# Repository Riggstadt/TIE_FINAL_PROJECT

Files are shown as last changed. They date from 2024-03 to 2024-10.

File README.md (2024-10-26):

# TIE FINAL PROJECT

This project was meant to familiarize us with PCB layout best practices and Design for Manufacturing (DFM).
<br>
  <p align="center">
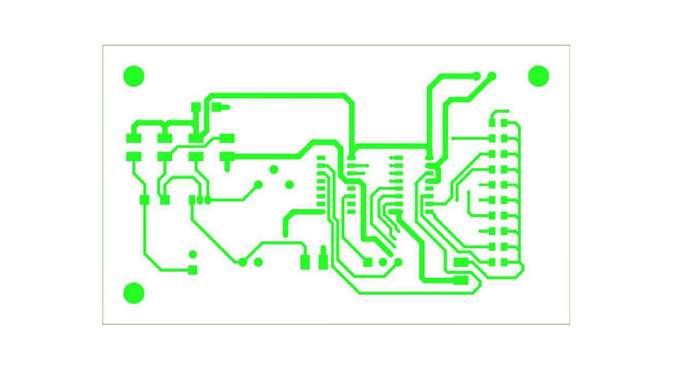
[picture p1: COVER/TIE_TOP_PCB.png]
    
    <br>
    <a><b>Top signal layer of PCB</b></a>
</p>
<br>

The final product of this project was a set of manufacturing files for PCB production, which was accompanied by a thorough technical documentation concerning circuit functionality and board design optimizations. 

This project served as the pelude to further PCB projects during my Electrotechnical Engineering degree, one of which can be seen <a href="https://github.com/Riggstadt/PROIECT_1_ETTI/tree/main">here</a>.

<br>
  <p align="center">
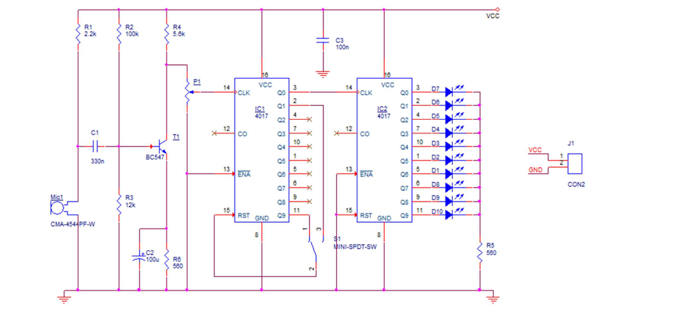
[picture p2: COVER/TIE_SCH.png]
    
    <br>
    <a><b>Circuit Schematic of Light Organ</b></a>
</p>
<br>

For a complete picture of the project, including sources and part inventory, please consult <a href="Orga de lumini.pdf">the documentation</a>.

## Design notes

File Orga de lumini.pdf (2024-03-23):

# UNIVERSITATEA POLITEHNICA DIN BUCUREȘTI

# ORGĂ DE LUMINI CU LED-URI

# Studenți: Frunză Vladimir, 423B Roncea Teodor Virgil, 423B

# Coordonator: Prof. Dr. Ing. Norocel Dragoș Codreanu An universitar: 2022-2023 Data de predare: 08.06.2023

## Facultatea de Electronică, Telecomunicații și Tehnologia Informației Departamentul de Electronică Tehnologică și Tehnici de Interconectare

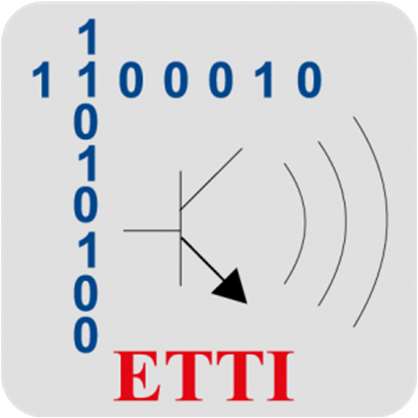
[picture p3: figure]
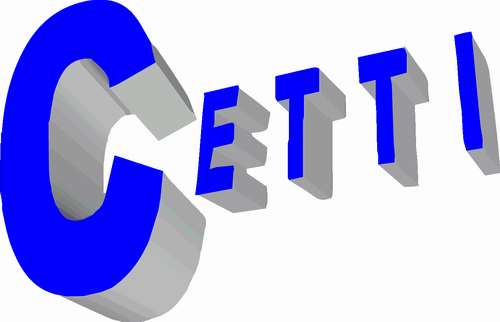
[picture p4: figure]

# CUPRINS

### I. Date iniale de proiectare | 1

II. | Descrierea a funconarii schemei proiectate | 2
III. | Schema electrica | 5
IV. | Design Rules Check (DRC) | 6

V. Cross Reference (CR) | 7 VI. Bill of Materials (BOM) | 9 VII. Wirelist (WR) | 10 VIII. Verificarea net-urilor | 16 IX. Layer TOP | 17 X. Layer BOTTOM | 18 XI. Layer Solder Mask TOP | 19 XII. Layer Solder Mask BOTTOM | 20 XIII. Layer Silk Screen TOP | 21 XIV. Layer Assembly Drawing TOP | 22 XV. Layer Fabricaon | 23 XVI. Concluzii | 24 XVII. Bibliografie | 25 XVIII. ANEXE | 26

# I. Date iniale de proiectare

Scopul proiectului de fata este de a realiza design-ul PCB al unei orgi de lumini cu LED-uri, conform unei scheme electrice si ai unor parametrii dati. Orga de lumini este realizata din mai multe blocuri functionale: captare semnal, amplificare semnal, reglare sensibilitate, divizor de frecventa si baterie de LED-uri.

PCB-ul o sa fie realizat din doua straturi electrice, TOP si BOTTOM. Toate componentele electrice vor fi plasate pe stratul TOP, traseele de semnal vor avea latimea de 0.5 mm, traseele de alimentare vor avea latimea de 0.9 mm, conexiunea cu masa se va realiza prin intermediul unor trasee de putere individuale, iar spatierea in toate cazurile va fi de 0.35 mm.

Placa va fi una dreptunghiulara cu latimea de 45 mm si lungimea de 75 mm, se vor plasa trei gauri de prindere nemetalizate cu un diametru de 3.2mm. Fiecare gaura se va afla la o distanta de 2M de coltul in care a fost plasat. Constrangerile de proiectare se pot vedea in ANEXA 2, randul 8.

In capitolele ce urmeaza se va prezenta o scurta descriere a circuitului, schema electrica echivalenta in programul OrCAD Capture si straturile electrice si non-electrice ale PCB-ului.

Schema electrica de realizat:

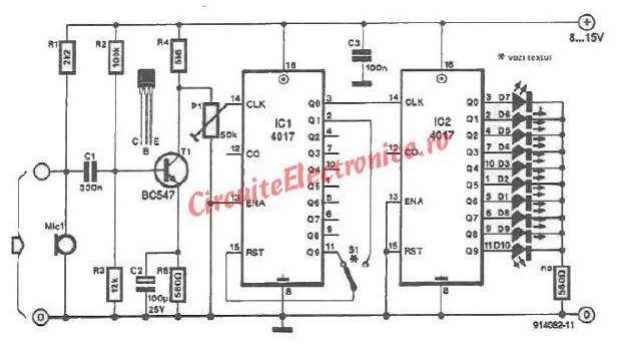
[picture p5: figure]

# II. Descriere a funconarii schemei proiectate

## a. Explicae la nivel general:

Circuitul din schema prezentata este al unei orgi de lumini cu LED-uri. Orga noastra produce jocul de lumini prin prelucrarea si “interpretarea” sunetelor prezente in mediul inconjurator.

Sunetele primite de microfon si amplificate de perechea preamplificator-amplificator au frecvente mult prea mari pentru a produce efecte vizibile. Vom utiliza doua numaratoare Johnson cascadate pe post de divizor de frecventa si vom reduce frecventa semnalului pana la un nivel la care jocurile de lumina or sa fie perceptibile vederii umane. Semnalul sonor primit de la amplificator va servi drept semnal de clock pentru primul circuit integrat. Cu ajutorul intrerupatorului SPDT vom alege in ce masura vom diviza frecventa de intrare.

## b. Explicae pe blocuri structurale:

Sunetul este transformat din simple vibratii in semnale electrice prin intermediul unui microfon tip electret, care prin variatia capacitatii stocate intre cele doua diafragme ale sale va genera semnalele electrice necesare prelucrarii.

Amplitudinea semnalului de iesire este foarte mica, de ordinul catorva zeci de microvolti. In interiorul capsulei comerciale este introdus un preamplificator simplu format dintr-un N-JFET. Cu ajutorul rezistorului R1 vom forma un amplificator sursa-comuna si defazaj 180 deg.

Pentru a ajunge la voltaje ce se pot considera logic HIGH vom introduce in circuit un amplificator emitor comun ce va amplifica semnalul la niveluri adecvate si va elimina defazajul de faza introdus de preamplificator.

Potentiometrul controleaza sensibilitatea circuitului la amplitudinea semnalului sonor,actionand ca un divizor de potential. Potentiometrul controleaza offset voltageul DC provenit de la VCC, asupra caruia este supraimpus semnalul AC amplificat.

Blocul divizor de frecventa reduce frecventa semnalului pentru a putea percepe in randul ledurilor un efect vizibil.

## c. Ilustrae blocuri structurale:

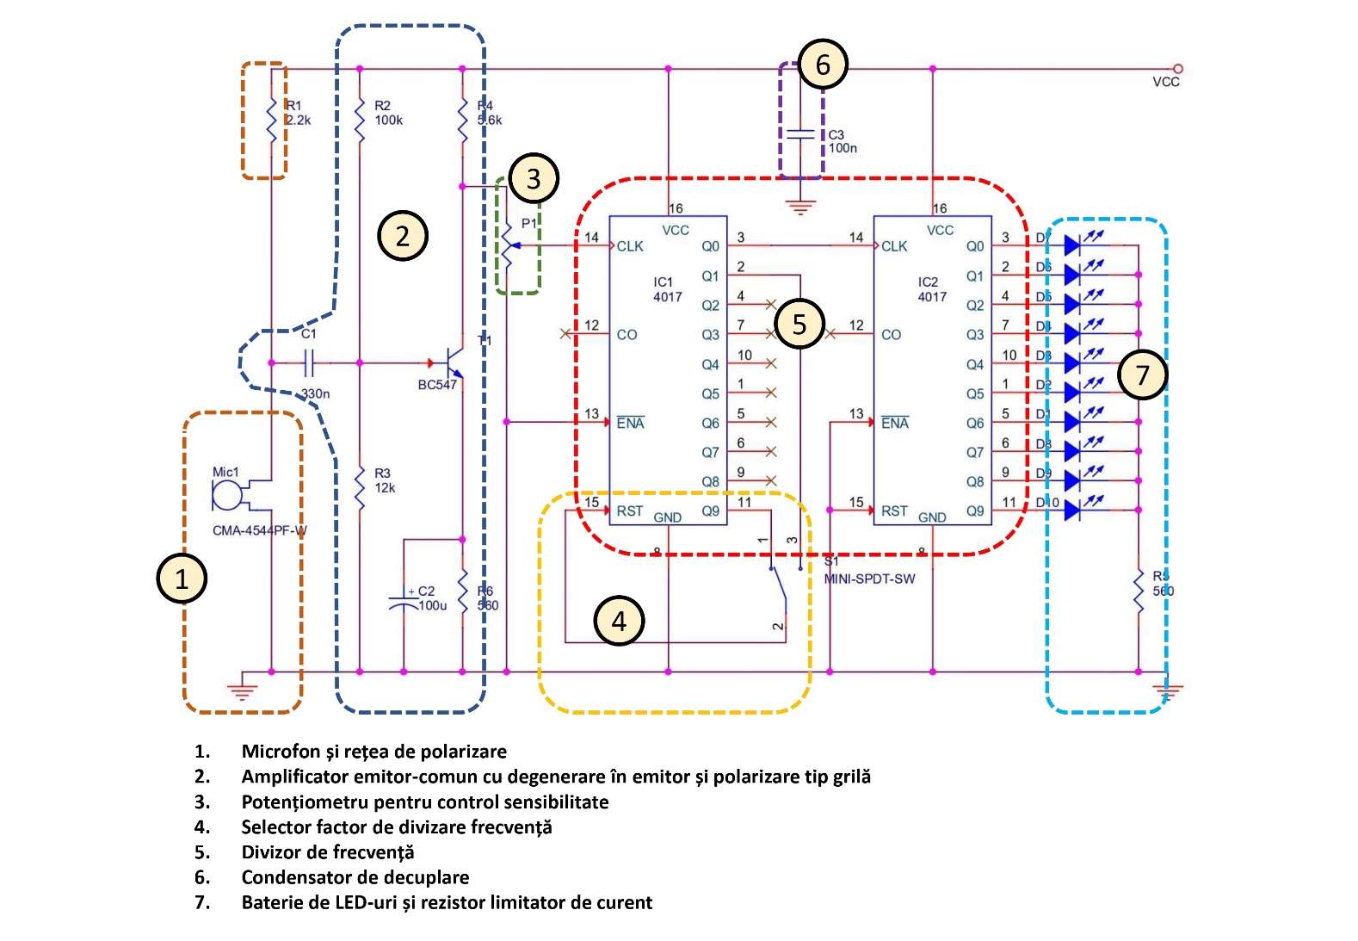
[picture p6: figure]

## d. Simulare funconalitate:

Schema electrica simplificata a circuitului a fost simulata cu ajutorul falstad.com pentru a mai bine intelege comportamentul circuitului si a vizualiza intr-o maniera facila oscilaa ledurilor.

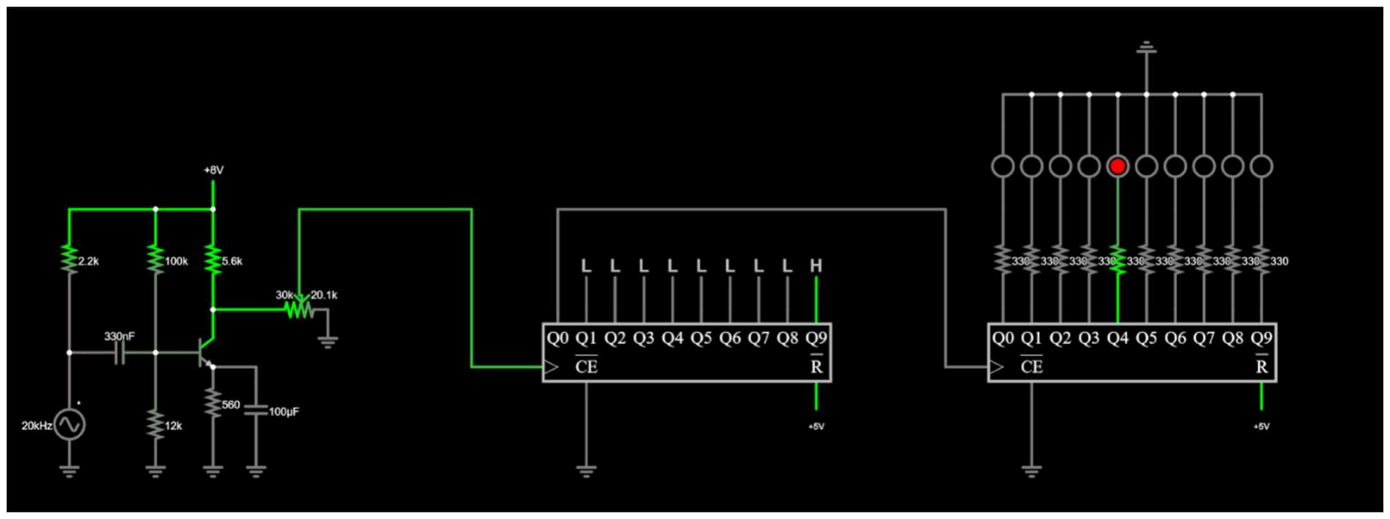
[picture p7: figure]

Rezultatele simularii sunt prezentate mai jos:

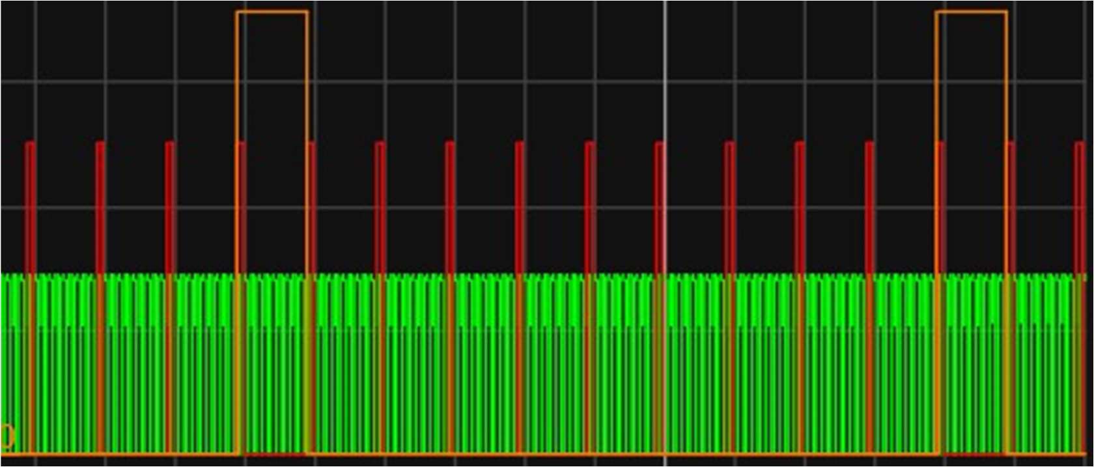
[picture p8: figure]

In verde, semnalul sinusoidal amplificat ce serveste drept clock pentru primul IC
In rosu, semnalul portului Q0 al primului IC ce prezinta reducerea in frecventa cu un factor de 10
In portocaliu, semnalul portului Q0 al celui de-al doilea IC prezinta reducerea in frecventa cu un factor de 100, semnalul va ne LED-ul deschis pana cand primul numarator se va reseta.

# III. Schema Electrica

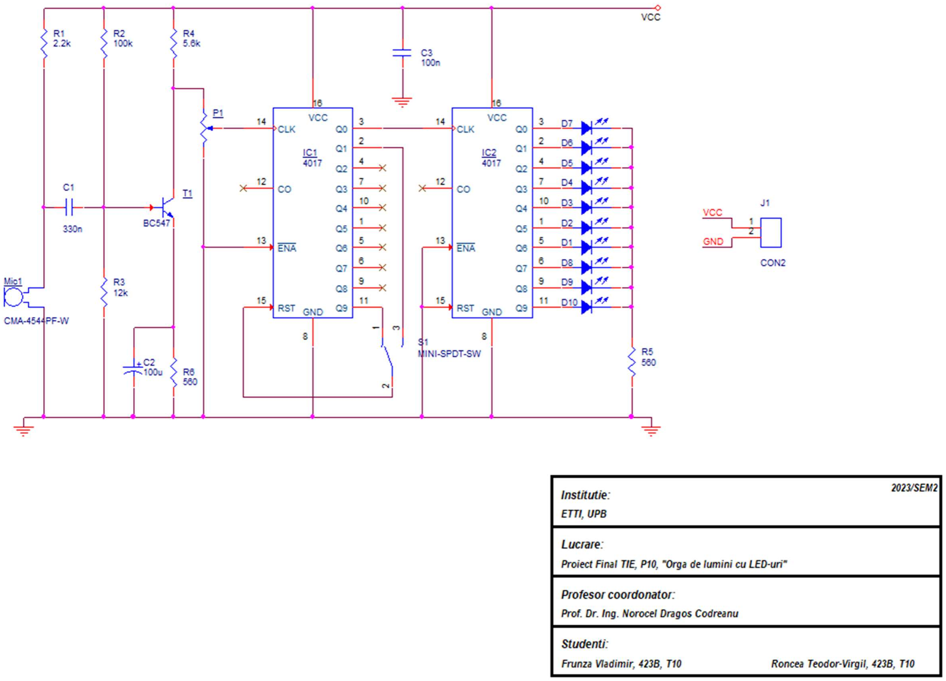
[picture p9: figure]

# IV. Design Rules Check (DRC)

## Date and Time : 06/07/23 21:48:02

## Checking Schemac: SCHEMATIC1

## Checking Electrical Rules

## Checking For Single Node Nets

## Checking For Unconnected Bus Nets

# V. Cross Reference

Design Name: D:\PROIECT_TIE\PROIECT\PROIECT FINAL TIE.DSN

Cross Reference | June 7,2023 21:41:22 Page1
Item Part | Reference | SchemacName | Sheet Library
____________________________________________________________________________
1 | 2.2k | R1 | SCHEMATIC1/PAGE1 | 0
E:\TCAD\TOOLS\CAPTURE\LIBRARY\DISCRETE.OLB
2 | 5.6k | R4 | SCHEMATIC1/PAGE1 | 0
E:\TCAD\TOOLS\CAPTURE\LIBRARY\DISCRETE.OLB
3 | 12k | R3 | SCHEMATIC1/PAGE1 | 0
E:\TCAD\TOOLS\CAPTURE\LIBRARY\DISCRETE.OLB
4 | 100k R2 | SCHEMATIC1/PAGE1 | 0
E:\TCAD\TOOLS\CAPTURE\LIBRARY\DISCRETE.OLB
5 | 100n C3 | SCHEMATIC1/PAGE1 | 0
E:\TCAD\TOOLS\CAPTURE\LIBRARY\DISCRETE.OLB
6 | 100u C2 | SCHEMATIC1/PAGE1 | 0
E:\TCAD\TOOLS\CAPTURE\LIBRARY\DISCRETE.OLB
7 | 330n C1 | SCHEMATIC1/PAGE1 | 0
E:\TCAD\TOOLS\CAPTURE\LIBRARY\DISCRETE.OLB
8 | 560 | R5 | SCHEMATIC1/PAGE1 | 0
E:\TCAD\TOOLS\CAPTURE\LIBRARY\DISCRETE.OLB
9 | 560 | R6 | SCHEMATIC1/PAGE1 | 0
E:\TCAD\TOOLS\CAPTURE\LIBRARY\DISCRETE.OLB
10 | 4017 IC1 | SCHEMATIC1/PAGE1 | 0
E:\CHESTII DE LE FAC LA TCAD\PROIECT FINAL TIE.DSN

11 | 4017 IC2 | SCHEMATIC1/PAGE1 | 0
E:\CHESTII DE LE FAC LA TCAD\PROIECT FINAL TIE.DSN
12 | BC547 T1 | SCHEMATIC1/PAGE1 | 0
E:\TCAD\TOOLS\CAPTURE\LIBRARY\TRANSISTOR.OLB
13 | CMA-4544PF-W Mic1 SCHEMATIC1/PAGE1 | 0
D:\PROIECT_TIE\PROIECT\CMA-4544PF-W.OLB
14 | CON2 J1 | SCHEMATIC1/PAGE1 | 0
D:\PROIECT_TIE\PROIECT\PROIECT FINAL TIE.DSN
15 | LED | D1 | SCHEMATIC1/PAGE1 | 0
E:\TCAD\TOOLS\CAPTURE\LIBRARY\DISCRETE.OLB
16 | LED | D2 | SCHEMATIC1/PAGE1 | 0
E:\TCAD\TOOLS\CAPTURE\LIBRARY\DISCRETE.OLB
17 | LED | D3 | SCHEMATIC1/PAGE1 | 0
E:\TCAD\TOOLS\CAPTURE\LIBRARY\DISCRETE.OLB
18 | LED | D4 | SCHEMATIC1/PAGE1 | 0
E:\TCAD\TOOLS\CAPTURE\LIBRARY\DISCRETE.OLB
19 | LED | D5 | SCHEMATIC1/PAGE1 | 0
E:\TCAD\TOOLS\CAPTURE\LIBRARY\DISCRETE.OLB
20 | LED | D6 | SCHEMATIC1/PAGE1 | 0
E:\TCAD\TOOLS\CAPTURE\LIBRARY\DISCRETE.OLB
21 | LED | D7 | SCHEMATIC1/PAGE1 | 0
E:\TCAD\TOOLS\CAPTURE\LIBRARY\DISCRETE.OLB
22 | LED | D8 | SCHEMATIC1/PAGE1 | 0
E:\TCAD\TOOLS\CAPTURE\LIBRARY\DISCRETE.OLB
23 | LED | D9 | SCHEMATIC1/PAGE1 | 0
E:\TCAD\TOOLS\CAPTURE\LIBRARY\DISCRETE.OLB
24 | LED | D10 | SCHEMATIC1/PAGE1 | 0
E:\TCAD\TOOLS\CAPTURE\LIBRARY\DISCRETE.OLB
25 | MINI-SPDT-SW S1 | SCHEMATIC1/PAGE1 | 0
D:\PROIECT_TIE\MINI-SPDT-SW\MINI-SPDT-SW.OLB
26 | POT | P1 | SCHEMATIC1/PAGE1 | 0
E:\TCAD\TOOLS\CAPTURE\LIBRARY\DISCRETE.OLB

Nr.curent | Cantitate | Referinta | Componenta | Descriere | Montare | Capsula | Producator | Distribuitor | Cod produs | Pret pe bucata (RON) | Cantitate minima | Pret comanda (RON)
1 | 1 | C1 | 330n | Multilayer Ceramic Capacitors MLCC - SMD/SMT 50V 0.33uF X7R 1206 10% | SMT | SMC1206 | KEMET | https://ro.mouser.com/ | C1206C334K5REC7210 | 1.58 | 1 | 1.58
2 | 1 | C2 | 100u | Aluminium Electrolytic Capacitors - Radial Leaded LOW IMPEDANCE ELECTROLYTIC CAPACITORS | THT | CAP196 | Rubycon | https://ro.mouser.com/ | 16ZLH100MEFC5X11 | 1.63 | 1 | 1.63
3 | 1 | C3 | 100n | Multilayer Ceramic Capacitors MLCC - SMD/SMT WCAP-CSST 1206 100nF 10% 100VDC | SMT | SMC1206 | Wurth Elektronik | https://ro.mouser.com/ | 885382208006 | 1.58 | 1 | 1.58
4 | 10 | D6,D7,D8,D9,D10 D1,D2,D3,D4,D5, | LED | LED, Low Power, Red, SMD, 0805 [2012 Metric], 20 mA, 2 V, 617 nm | SMT | SML0805 | Kingbright | https://ro.farnell.com/ | KP-2012EC | 0,8687 | 5 | 8.69
5 | 2 | IC1,IC2 | 4017 | Counter ICs 10 Decade/Divider | SMT | SOIC16 | TI | https://ro.mouser.com/ | CD4017BNSR | 4.51 | 1 | 9.02
6 | 1 | J1 | CON2 | TERM BLK 2P SIDE ENT 2.54MM PCB | THT | JUMPER2 | TE Connectivity | https://www.digikey.ro/ | 282834-2 | 6.36 | 1 | 6.36
7 | 1 | Mic1 | CMA-4544PF-W | MIC COND ANLG OMNI -44DB 0.382"D | THT | MIC_CMA-4544PF-W | CUI Devices | https://www.digikey.ro/ | CMA-4544PF-W | 3.6 | 1 | 3.6
8 | 1 | P1 | POT | Trimmer Resistors - Through Hole 50Kohms 10mm Rnd Top adj Steel Lead | THT | POT | Amphenol | https://ro.mouser.com/ | PT10LV10-503A2020-S | 2.62 | 1 | 2.62
9 | 1 | R1 | 2.2k | Thick Film Resistors - SMD 1206 5% 2.2Kohm Anti-Sulfur AEC-Q200 | THT | SMD1206 | Panasonic | https://ro.mouser.com/ | ERJ-U08J222V | 0.89 | 1 | 0.89
10 | 1 | R2 | 100k | Thick Film Resistors - SMD ResPowerQ 1206 100k 1% 1/2W TC100 | THT | SMD1206 | Bourns | https://ro.mouser.com/ | CRM1206QFX-1003ELF | 1.02 | 1 | 1.02
11 | 1 | R3 | 12k | Thick Film Resistors - SMD 1206 12Kohm 1% Anti Surge AEC-Q200 | THT | SMD1206 | ROHM Semicond. | https://ro.mouser.com/ | ESR18EZPF1202 | 0.79 | 1 | 0.79
12 | 1 | R4 | 5.6k | Thick Film Resistors - SMD 1206 5.6Kohm 5% High VoltageAEC-Q200 | THT | SMD1206 | ROHM Semicond. | https://ro.mouser.com/ | KTR18EZPJ562 | 0.74 | 1 | 0.74
13 | 2 | R5,R6 | 560 | Thick Film Resistors - SMD 1/4Watt 560ohms 1% Commercial Use | THT | SMD1206 | Vishay | https://ro.mouser.com/ | CRCW1206560RFKEAC | 0.51 | 1 | 1.02
14 | 1 | S1 | MINI-SPDT-SW | Slide Switches MINI SPDT SWITCH | THT | MINI-SPDT-SW | Gravitech | https://ro.mouser.com/ | SW_MINI-SPDT-SW | 14.6 | 1 | 14.6
15 | 1 | T1 | BC547 | Bipolar Transistors - BJT NPN 45V 100mA HFE/45 | THT | TO92 | Fairchild | https://ro.mouser.com/ | BC547B | 2.19 | 1 | 2.19
* | Foile de catalog pentru CD4017, BC547B si CMA-45544PF-W sunt prezentate intr-o forma scurtata in ANEXELE: | Total (RON): | 56.33
**
*** | In estimarea costului total nu sunt incluse taxele de livrare Foile de catalog pentru toate componentele se gasesc in forma lor completa pe stcikul usb

# VI. Wire List

Wire List

Revised: Wednesday, June 07, 2023 C:\USERS\VLADY\DESKTOP\PROIECT\PROIECT FINAL TRevision:

<<< Component List >>>
330n | C1 | SMC1206
100u | C2 | CAP196
100n | C3 | SMC1206
LED | D1 | SML0805
LED | D10 | SML0805
LED | D2 | SML0805
LED | D3 | SML0805
LED | D4 | SML0805
LED | D5 | SML0805
LED | D6 | SML0805
LED | D7 | SML0805
LED | D8 | SML0805
LED | D9 | SML0805
4017 | IC1 | SOIC16
4017 | IC2 | SOIC16
CON2 | J1 | JUMPER2
CMA-4544PF-W | | Mic1 MIC_CMA-4544PF-W
POT | P1 | POT
2.2k | R1 | SMD120612

100k | | R2 | SMD120612
12k | R3 | SMD120612
5.6k | R4 | SMD120612
560 | R5 | SMD120612
560 | R6 | SMD120612
MINI-SPDT-SW | S1 | SW_MINI-SPDT-SW
BC547 | | T1 | TO92

<<< Wire List >>>

NODE REFERENCE PIN # PIN NAME | PIN TYPE | PART VALUE
[00001] GND
R3 | 2 | 2 | Passive | 12k
R5 | 2 | 2 | Passive | 560
R6 | 2 | 2 | Passive | 560
C2 | 2 | 2 | Passive | 100u
C3 | 2 | 2 | Passive | 100n
P1 | 3 | B | Passive | POT
IC2 | 13 E\N\A\ | Input | 4017
IC2 | 15 RST | Input | 4017
IC2 | 8 | GND | Power | 4017
IC1 | 13 E\N\A\ | Input | 4017
IC1 | 8 | GND | Power | 4017
J1 | 2 | 2 | Power | CON2
Mic1 | 2 | GND | Power | CMA-4544PF-W

[00002] N0043710
IC2 | 6 | Q7 | Output | 4017
D8 | 1 | ANODE | Passive | LED
[00003] N0043711
IC2 | 9 | Q8 | Output | 4017
D9 | 1 | ANODE | Passive | LED
[00004] N0043712
IC2 | 11 Q9 | Output | 4017
D10 | 1 | ANODE | Passive | LED
[00005] N004373
IC2 | 3 | Q0 | Output | 4017
D7 | 1 | ANODE | Passive | LED
[00006] N004374
IC2 | 2 | Q1 | Output | 4017
D6 | 1 | ANODE | Passive | LED
[00007] N004375
IC2 | 4 | Q2 | Output | 4017
D5 | 1 | ANODE | Passive | LED
[00008] N004376
IC2 | 7 | Q3 | Output | 4017
D4 | 1 | ANODE | Passive | LED

[00009] N004377
IC2 | 10 Q4 | Output | 4017
D3 | 1 | ANODE | Passive | LED
[00010] N004378
IC2 | 1 | Q5 | Output | 4017
D2 | 1 | ANODE | Passive | LED
[00011] N004379
IC2 | 5 | Q6 | Output | 4017
D1 | 1 | ANODE | Passive | LED
[00012] N01138
R5 | 1 | 1 | Passive | 560
D1 | 2 | CATHODE | Passive | LED
D2 | 2 | CATHODE | Passive | LED
D3 | 2 | CATHODE | Passive | LED
D4 | 2 | CATHODE | Passive | LED
D5 | 2 | CATHODE | Passive | LED
D6 | 2 | CATHODE | Passive | LED
D7 | 2 | CATHODE | Passive | LED
D8 | 2 | CATHODE | Passive | LED
D9 | 2 | CATHODE | Passive | LED
D10 | 2 | CATHODE | Passive | LED
[00013] N02847
IC2 | 14 CLK | Input | 4017
IC1 | 3 | Q0 | Output | 4017

[00014] N02937
IC1 | 11 Q9 | Output | 4017
S1 | 1 | 1 | Passive | MINI-SPDT-SW
[00015] N02945
IC1 | 2 | Q1 | Output | 4017
S1 | 3 | 3 | Passive | MINI-SPDT-SW
[00016] N03485
IC1 | 15 RST | Input | 4017
S1 | 2 | 2 | Passive | MINI-SPDT-SW
[00017] N03522
P1 | 2 | WIPER | Passive | POT
IC1 | 14 CLK | Input | 4017
[00018] N04274
R4 | 2 | 2 | Passive | 5.6k
T1 | 3 | COLLECTOR | Passive | BC547
P1 | 1 | A | Passive | POT
[00019] N04307
R6 | 1 | 1 | Passive | 560
C2 | 1 | 1 | Passive | 100u
T1 | 1 | EMITTER | Passive | BC547

[00020] N04445
R2 | 2 | 2 | Passive | 100k
R3 | 1 | 1 | Passive | 12k
C1 | 1 | 1 | Passive | 330n
T1 | 2 | BASE | Input | BC547
[00021] N04471
R1 | 2 | 2 | Passive | 2.2k
C1 | 2 | 2 | Passive | 330n
Mic1 | 1 | OUT | Output | CMA-4544PF-W
[00022] VCC
R1 | 1 | 1 | Passive | 2.2k
R2 | 1 | 1 | Passive | 100k
R4 | 1 | 1 | Passive | 5.6k
C3 | 1 | 1 | Passive | 100n
IC2 | 16 VCC | Power | 4017
IC1 | 16 VCC | Power | 4017
J1 | 1 | 1 | Power | CON2

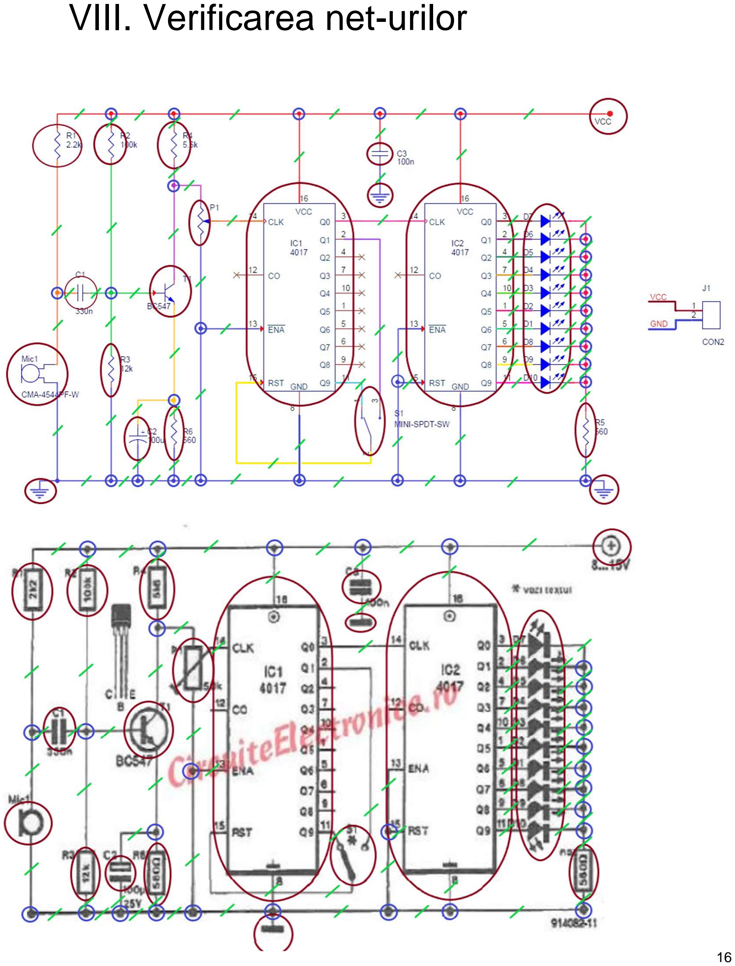
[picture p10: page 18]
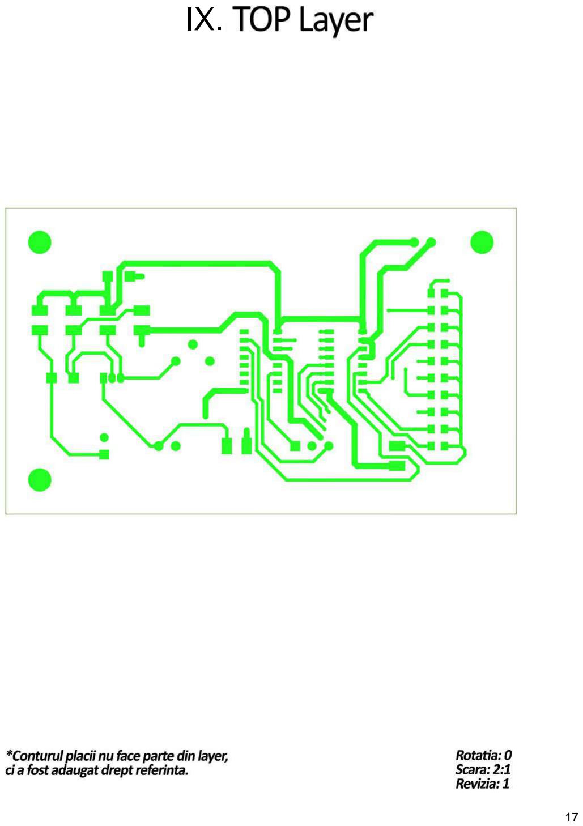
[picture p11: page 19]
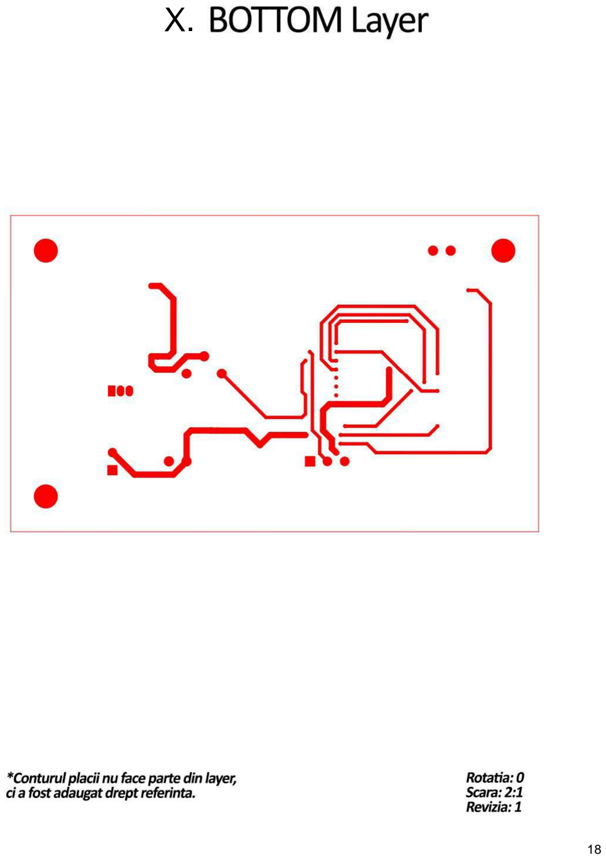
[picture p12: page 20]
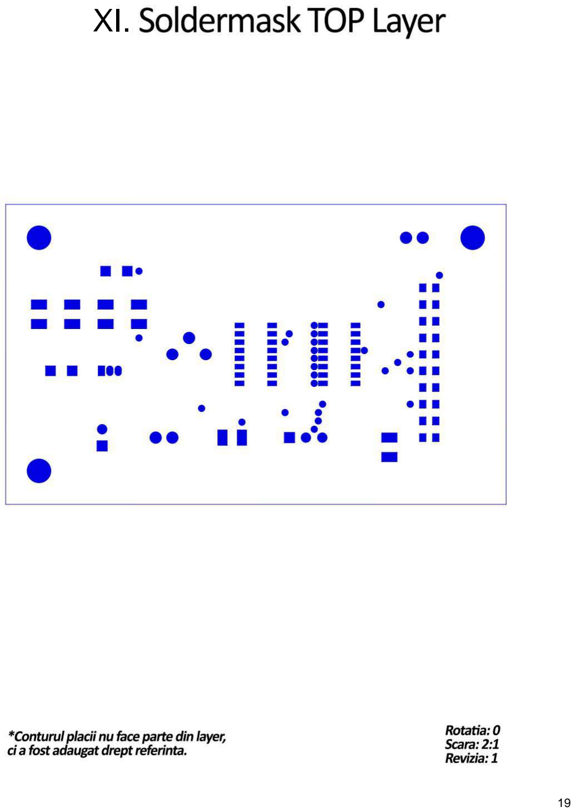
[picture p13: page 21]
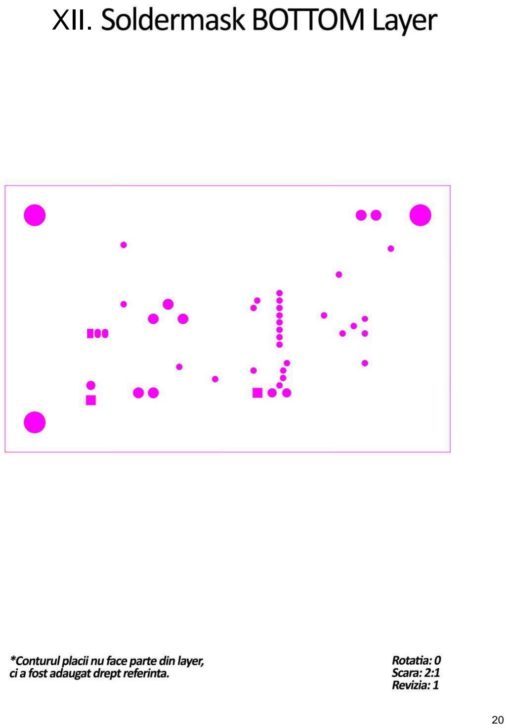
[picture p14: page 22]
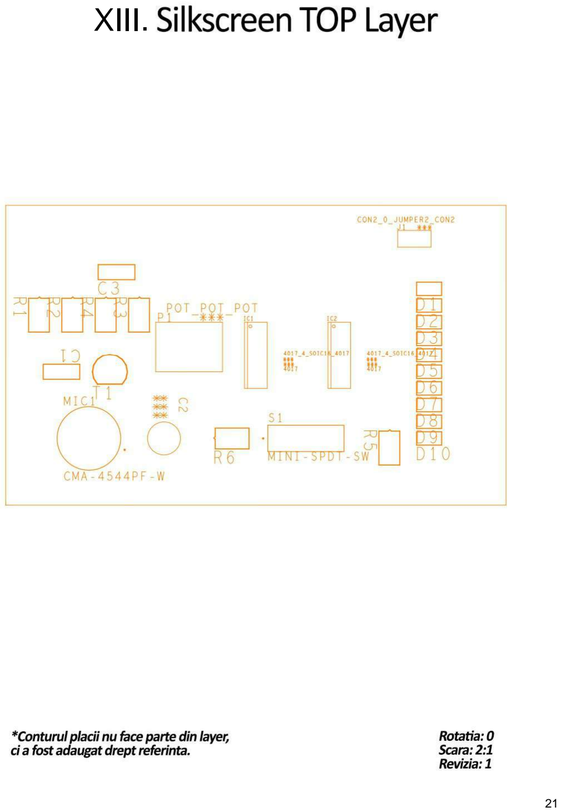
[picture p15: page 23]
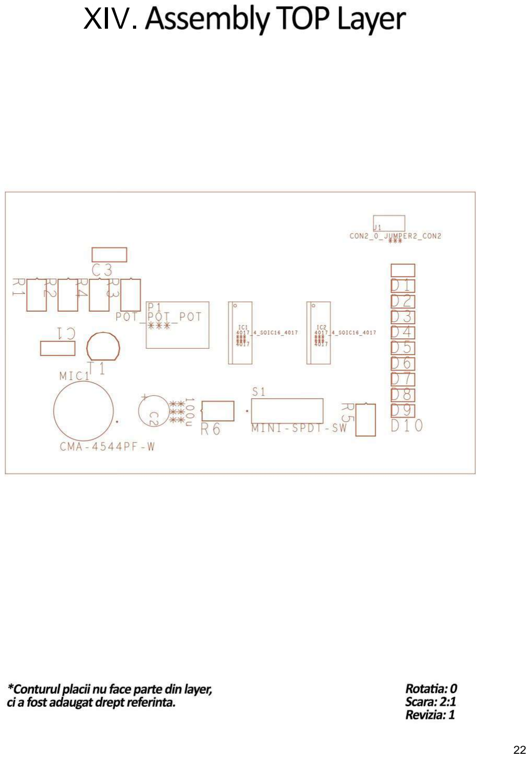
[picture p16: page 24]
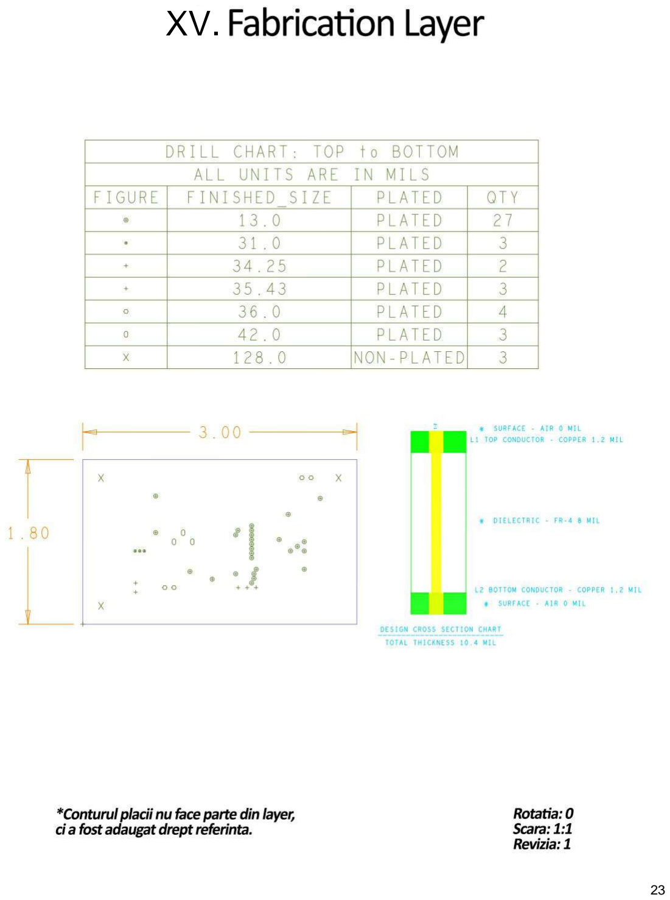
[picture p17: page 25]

# XVI. Concluzii

### In proiectarea PCB a unui modul electronic este necesara o atene deosebita la detalii. Chiar si cele mai simple proiecte necesita un nivel ridicat de

atene si implicare. Trebuie urmate intotdeauna normele specifice industriei, asel incat calitatea produsului final sa nu fie degradata.

### Etapa de proiectare a PCB-ului este foarte importanta din perspecva costurilor in mpul etapei de produce pe scara larga. Erorile sau defecunile introduse accidental in etapa de proiectare vor conduce la retragerea produsului

din circulae si vor implica lucrari remediale cossitoare.

Pentru realizarea acestui proiect au fost folosite in special programe aparnand ecosistemului CADENCE, precum: Orcad Capture CIS Lite si Orcad PCB Designer Lite. Ulizat frecvent in industrie, ecosistemul CADENCE este recunoscut pentru multudinea sa de unelte si instrumente, ideale folosirii in cadrul unor

proiecte de complexitate ridicata.

# XVII. Bibliografie

### - Functionare si best practices pentru microfoane de tip electret:

https://www.ti.com/lit/ug/tidu765/tidu765.pdf

### - Introducere facila a utilizarii circuitului integrat CD4017:

https://www.build-electronic-circuits.com/4000-series-integrated-circuits/ic-4017/

### - Sursa footprint-uri PCB:

https://www.snapeda.com/

Utilizand circuitul CMOS 4017 si cateva component electronice passive, poate fi realizata o orga de lumini cu Led-uri. Aceasta orga de lumen cu LED-uri este comandata de un semnal ce este preluat cu ajutorul unui microfon.

Viteza de deplasare a luminii depinde de frecventa si intensitatea sunetului.
Semnalul se aplica la intrarea de tact a numaratorului IC1 printr-un amplificator cu un singur tranzistor, T1.

Dupa amplificare, semnalul este aplicat la IC1, prin P1, care controleaza sensibilitatea circuitului. Deoarece frecventele audio sunt prea mari pentru a produce un efect vizual de calitate, frecventa semnalului este demultiplicata cu IC1 atunci cand S1 conecteaza pinul 11 cu pinul 15.

Din cele zece iesiri ale lui IC2, fiecare cuplata la cate un LED, exista intotdeauna una in starea 1.

Sursa de alimentare trebuie sa poata furniza un curent de pana la 100 mA.

Schema Electronica:

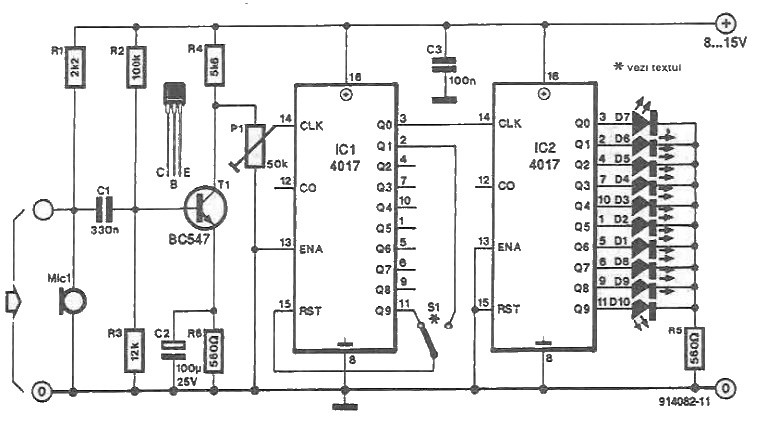
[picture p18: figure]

# Specificaţii şi valori pentru proiect (anexa 2)

Echipa (“Team”) | 2.3 [mm] | 2.4 [mm] | 2.5 [mm] | 3.1, 3.2: forma şi dimensiunile plăcii [mm] & info cu privire la găurile de prindere (g.p.)
1 | 0,2 | 1,2 | 0,40 | Dreptunghi, 70x50, cu 3 g.p. în 3 colţuri, plasate la 2 M distanţă de colţuri*
2 | 0,3 | 1,1 | 0,35 | Dreptunghi, 70x55, cu 4 g.p. în cele 4 colţuri, plasate la 1,5 M distanţă de colţuri*
3 | 0,4 | 1,0 | 0,25 | Dreptunghi, 70x60, cu 2 g.p. în 2 colţuri pe diagonală, plasate la 1,5 M distanţă de colţuri*
4 | 0,5 | 0,9 | 0,40 | Pătrat, 65x65, cu 4 g.p. în cele 4 colţuri, plasate la 2 M distanţă de colţuri*
5 | 0,2 | 1,2 | 0,35 | Pătrat, 50x50, cu 2 g.p. în 2 colţuri pe diagonală, plasate la 2 M distanţă de colţuri*
6 | 0,3 | 1,1 | 0,25 | Pătrat, 60x60, cu 3 g.p. în 3 colţuri, plasate la 1,5 M distanţă de colţuri*
7 | 0,4 | 1,0 | 0,40 | Dreptunghi, 65x55, cu 4 g.p. în cele 4 colţuri, plasate la 1,5 M distanţă de colţuri*
8 | 0,5 | 0,9 | 0,35 | Dreptunghi, 75x45, cu 3 g.p. în 3 colţuri, plasate la 2 M distanţă de colţuri*
9 | 0,2 | 1,2 | 0,25 | Dreptunghi, 70x55, cu 2 g.p. în 2 colţuri pe diagonală, plasate la 2 M distanţă de colţuri*
10 | 0,3 | 1,1 | 0,40 | Pătrat, 70x70, cu 3 g.p. în 3 colţuri, plasate la 2 M distanţă de colţuri*
11 | 0,4 | 1,0 | 0,35 | Pătrat, 55x55, cu 4 g.p. în cele 4 colţuri, plasate la 1,5 M distanţă de colţuri*
12 | 0,5 | 0,9 | 0,25 | Pătrat, 65x65, cu 2 g.p. în 2 colţuri pe diagonală, plasate la 1,5 M distanţă de colţuri*
13 | 0,2 | 1,1 | 0,40 | Dreptunghi, 75x45, cu 2 g.p. în 2 colţuri pe diagonală, plasate la 2 M distanţă de colţuri*
14 | 0,25 | 1,2 | 0,35 | Dreptunghi, 75x60, cu 4 g.p. în colţuri, plasate la 2 M distanţă de colţuri*
15 | 0,35 | 1,0 | 0,3 | Pătrat, 75X75, cu 3 g.p. în 3 colţuri, plasate la 1,5 M distanţă de colţuri*

* OBS: Distanţa față de colț (de fapt, orice distanță în electronică) se calculează pe principiul “centru la centru”, deci, în acest caz, “colț la centrul găurii de prindere”.

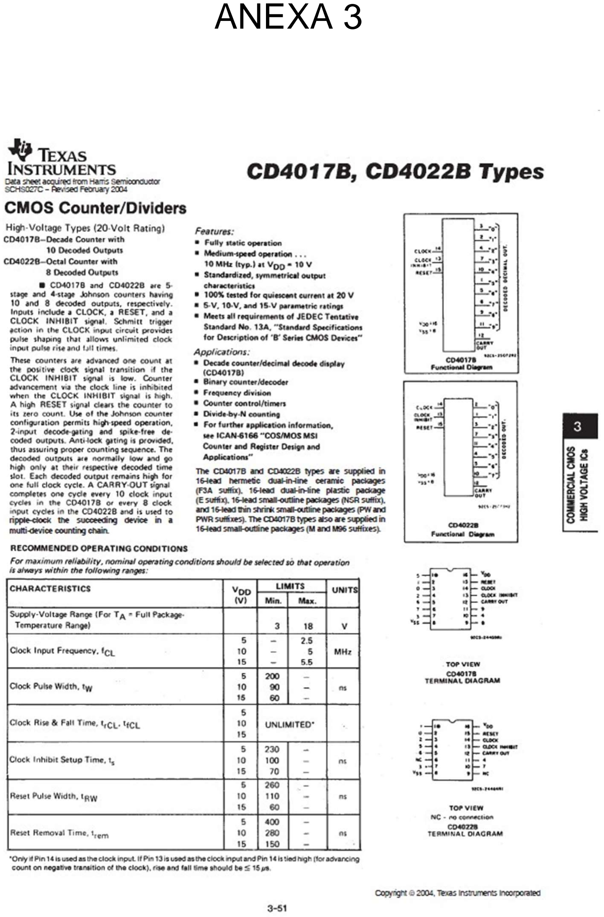
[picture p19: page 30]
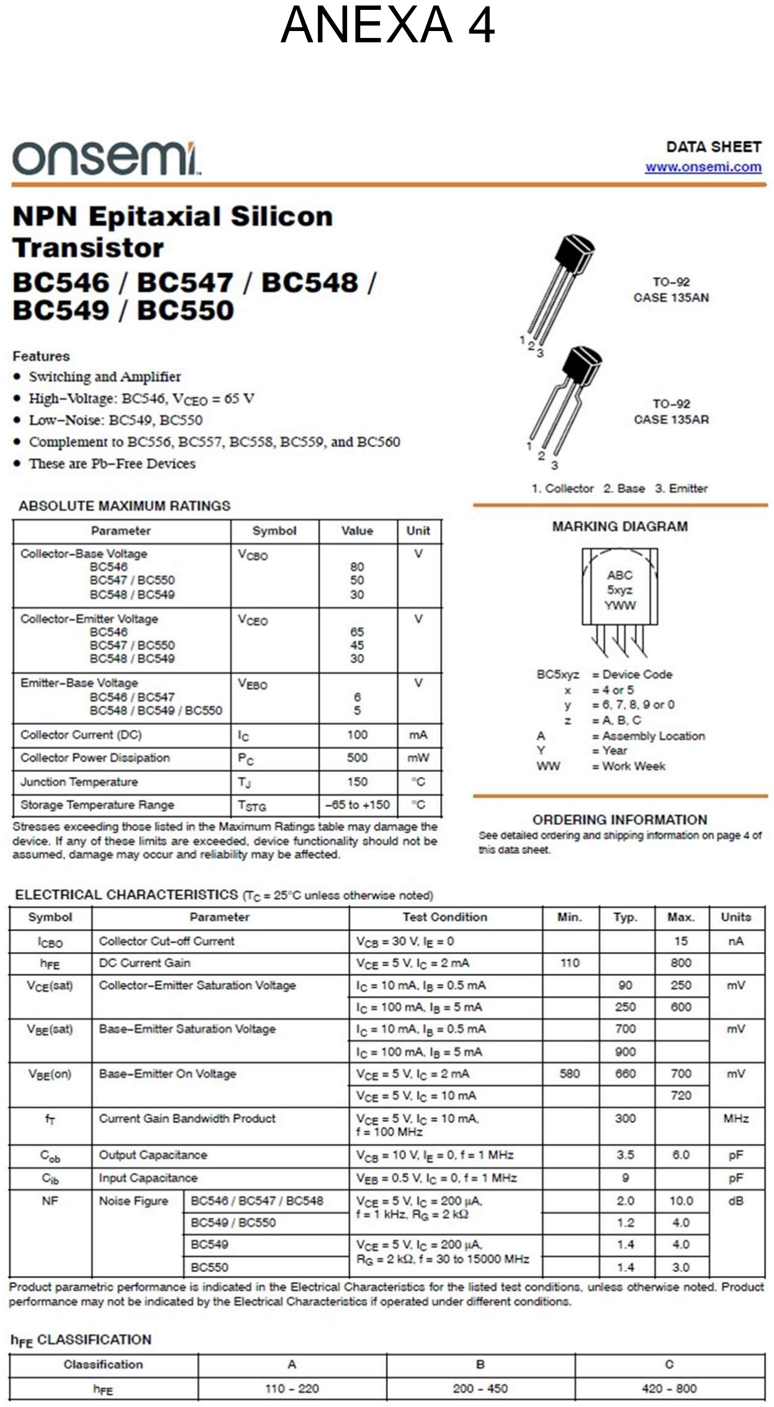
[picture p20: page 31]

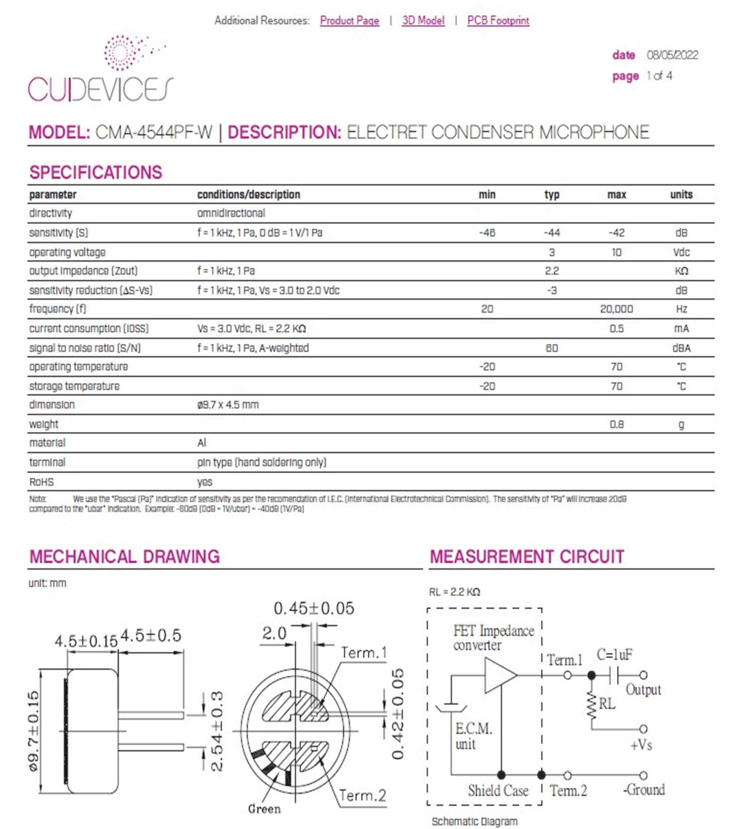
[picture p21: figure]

Componenta LINK WEB
T1 | https://ro.mouser.com/ProductDetail/onsemi-Fairchild/BC547B?qs=UMEuL5FsraB3zD25tclGGQ%3D%3D
LEDS | https://ro.farnell.com/kingbright/kp-2012ec/led-0805-red-15mcd-625nm/dp/8529949
MIC | https://www.digikey.ro/en/products/detail/cui-devices/CMA-4544PF-W/1869981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
SPDT | https://ro.mouser.com/ProductDetail/Gravitech/MINI-SPDT-SW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
C3 | https://ro.mouser.com/ProductDetail/Wurth-Elektronik/885382208006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
C1 | https://ro.mouser.com/ProductDetail/KEMET/C1206C334K5REC7210?qs=55YtniHzbhDHbCvaZ9e%2FFA%3D%3D
C2 | https://ro.mouser.com/ProductDetail/Rubycon/16ZLH100MEFC5X11?qs=T3oQrply3y%252BqHkLqRu3b6g%3D%3D
CD4017 | https://ro.mouser.com/ProductDetail/Texas-Instruments/CD4017BNSR?qs=afYny40WCj0TlPXA7Qbixg%3D%3D
CON2 | https://www.digikey.ro/en/products/detail/te-connectivity-amp-connectors/282834-2/1150135
POT | https://ro.mouser.com/ProductDetail/Amphenol-Piher/PT10LV10-503A2020-S?qs=pCZPOPZMYPjqzVGtfP%2FqKQ%3D%3D
R5,R6 | https://ro.mouser.com/ProductDetail/Vishay-Dale/CRCW1206560RFKEAC?qs=E3Y5ESvWgWPfLhzRynA%252BNw%3D%3D
R1 | https://ro.mouser.com/ProductDetail/Panasonic/ERJ-8ENF2201V?qs=JjxTDIFmKPQcNl%2Fy2Low0A%3D%3D
R2 | https://ro.mouser.com/ProductDetail/Bourns/CRM1206QFX-1003ELF?qs=8Wlm6%252BaMh8RndkZYFfPU1w%3D%3D
R3 | https://ro.mouser.com/ProductDetail/ROHM-Semiconductor/ESR18EZPF1202?qs=493kPxzlxfK7LOCMNV3P3Q%3D%3D
R4 | https://ro.mouser.com/ProductDetail/ROHM-Semiconductor/KTR18EZPJ562?qs=DyUWGjl%252BcVuZPnCDNYiZBA%3D%3D

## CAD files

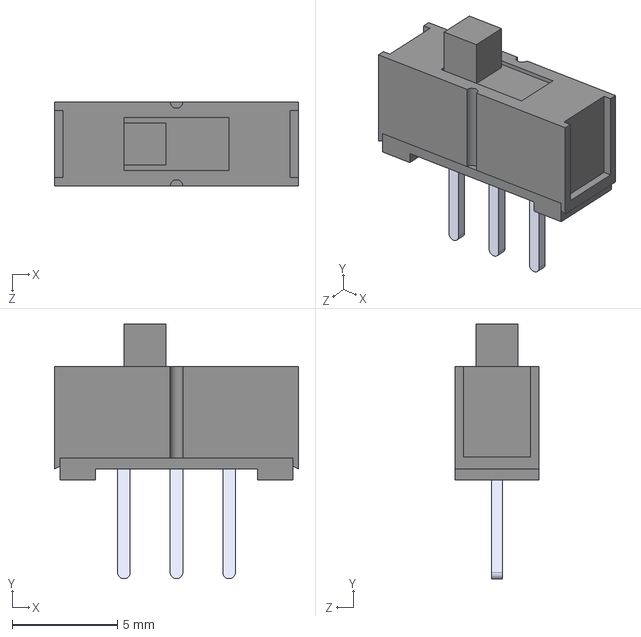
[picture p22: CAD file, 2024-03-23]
DESIGN_FILES/MINI-SPDT-SW.STEP
11.6 x 12.1 x 4.00 mm

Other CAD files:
DESIGN_FILES/mic_cma-4544pf-w.psm
DESIGN_FILES/sw_mini-spdt-sw.psm
